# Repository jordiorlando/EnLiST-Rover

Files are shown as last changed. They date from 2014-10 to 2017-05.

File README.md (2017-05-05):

EnLiST-Rover
============

EnLiST Rover modelled on the Curiosity Rover. The goal is to use it as a teaching platform for middle and high school students.

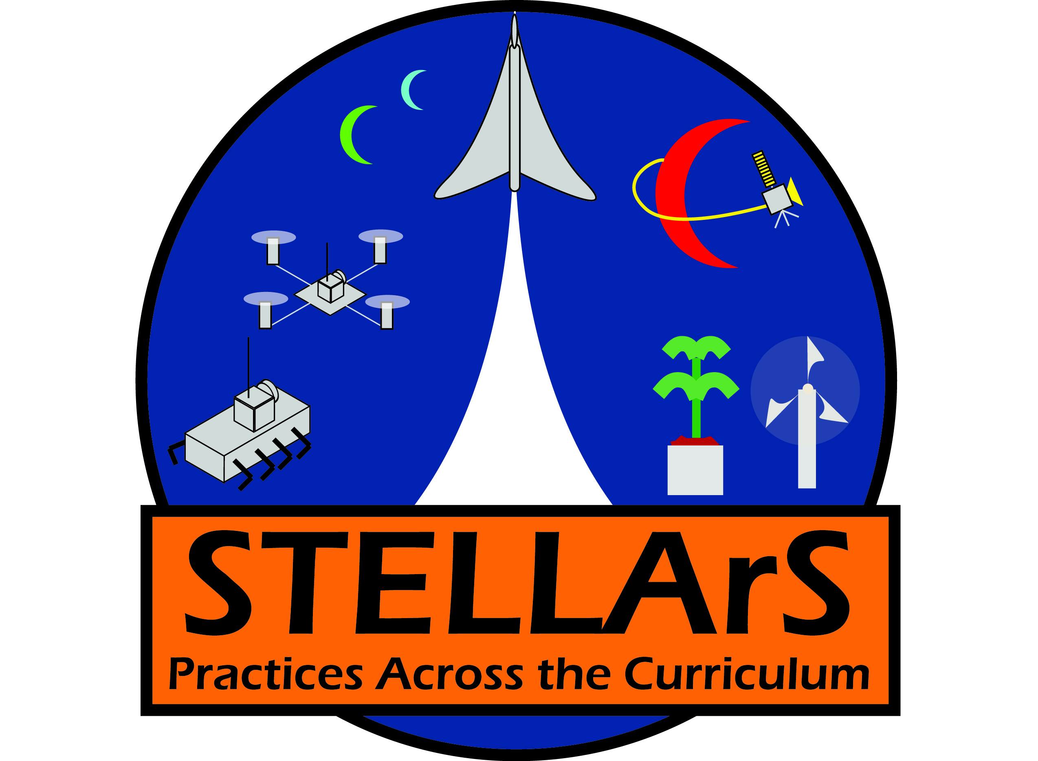
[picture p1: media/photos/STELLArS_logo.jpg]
STELLArS Logo


## Motor Controller
[Motor Controller Test Video](https://www.youtube.com/watch?v=swelm4EhzFY) demonstrating PC simulation and gamepad interface.

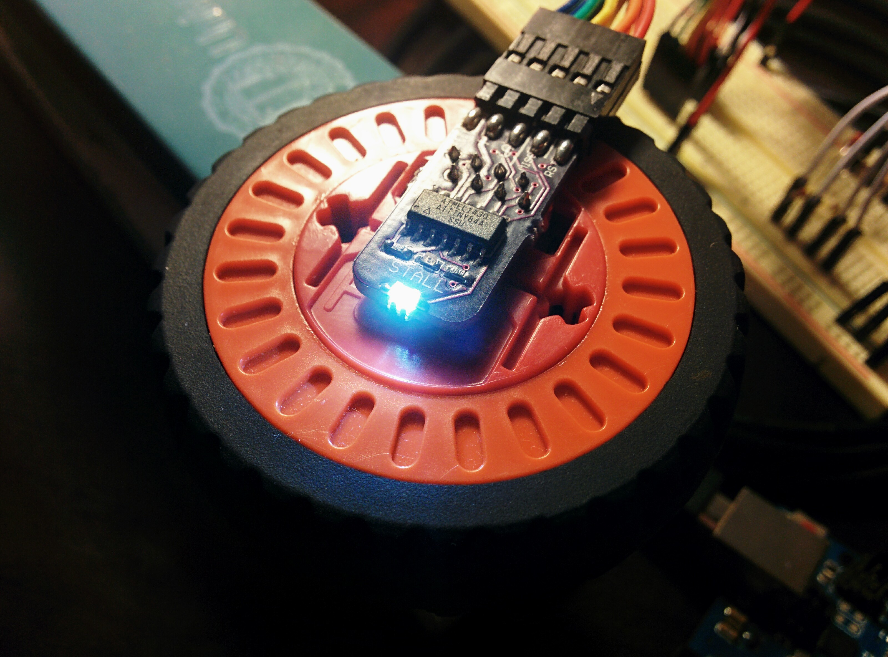
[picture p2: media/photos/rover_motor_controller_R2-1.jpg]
Motor Controller R2 1

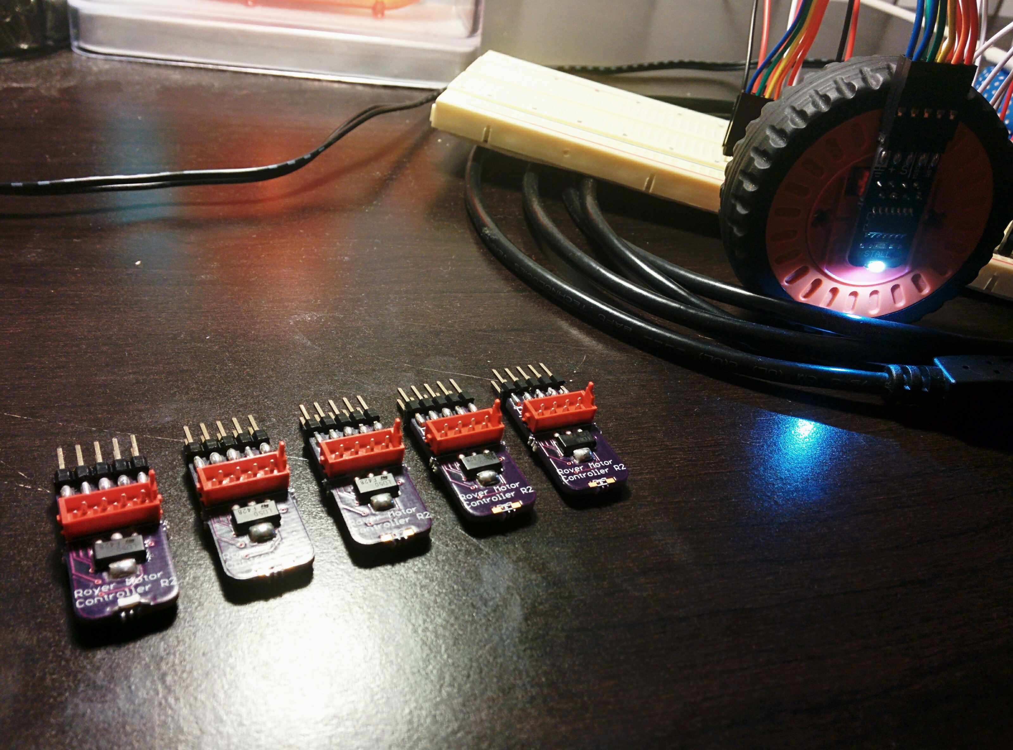
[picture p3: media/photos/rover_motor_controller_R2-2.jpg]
Motor Controller R2 2


## Prototype Photos
Rover Prototype 1
Rover Prototype 2
Rover Prototype 3

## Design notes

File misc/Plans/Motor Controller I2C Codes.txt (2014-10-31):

Standby         - 0x00
Freewheel       - 0x01
Brake           - 0x02
Turn Forwards   - 0x03
Turn Backwards  - 0x04
Set Servo       - 0x05
Turn Off Lamp   - 0x06
Turn On Lamp    - 0x07

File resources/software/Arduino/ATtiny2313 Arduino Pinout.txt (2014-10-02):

ATtiny2313 Arduino Pinout
			  __  __
			 |  \/  |
	   RST	1|		|20	 VCC
		D0	2|		|19	 D16
		D1	3|		|18	 D15
		D2	4|		|17	 D14
		D3	5|		|16	 D13~
		D4	6|		|15	 D12~
		D5	7|		|14	 D11~
		D6	8|		|13	 D10
	   ~D7	9|		|12	 D9
	   GND 10|		|11  D8
	   		 |______|

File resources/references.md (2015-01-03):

Chassis:<br>
http://www.creative-robotics.com/bmdsresources

BBB:<br>
https://learn.sparkfun.com/tutorials/i2c<br>
http://derekmolloy.ie/beaglebone/beaglebone-an-i2c-tutorial-interfacing-to-a-bma180-accelerometer/

http://derekmolloy.ie/beaglebone-images-video-and-opencv/<br>
http://derekmolloy.ie/beaglebone/beaglebone-video-capture-and-image-processing-on-embedded-linux-using-opencv/

http://www.element14.com/community/community/designcenter/single-board-computers/next-gen_beaglebone/blog/2013/08/10/bbb--rechargeable-on-board-battery-system

Motor Controllers:<br>
http://highlowtech.org/?p=1695

http://playground.arduino.cc/Code/USIi2c<br>
http://www.instructables.com/id/ATTiny-USI-I2C-The-detailed-in-depth-and-infor/

http://playground.arduino.cc/Code/PIDLibrary

https://code.google.com/p/adaencoder/<br>
http://www.pjrc.com/teensy/td_libs_Encoder.html<br>
http://thewanderingengineer.com/2013/05/05/rotary-encoder-with-the-attiny85/<br>
http://runawaybrainz.blogspot.com/2013/08/avr-attiny-2313-v-usb-media-volume.html

Servos:<br>
http://www.adafruit.com/products/815

Dust Sensor:<br>
http://www.howmuchsnow.com/arduino/airquality/<br>
http://arduinodev.woofex.net/2012/12/01/standalone-sharp-dust-sensor/<br>
https://www.sparkfun.com/datasheets/Sensors/gp2y1010au_e.pdf

Web Frontend:<br>
http://httpd.apache.org/<br>
http://ami.responsivedesign.is/<br>
http://www.google.com/design/spec/material-design/introduction.html<br>
https://www.polymer-project.org/<br>
https://developers.google.com/blockly/<br>
https://github.com/nnnick/Chart.js<br>
https://github.com/flatiron/director

http://maklesoft.github.io/padlock/<br>
https://github.com/MaKleSoft/shape-shifter<br>
http://codepen.io/anon/pen/qJDsg<br>
http://codepen.io/kabadesu/pen/qvdzK<br>
https://github.com/Battlefy/paper-vertical-tabs

Misc:<br>
http://blog.oscarliang.net/program-attiny2313-using-arduino/

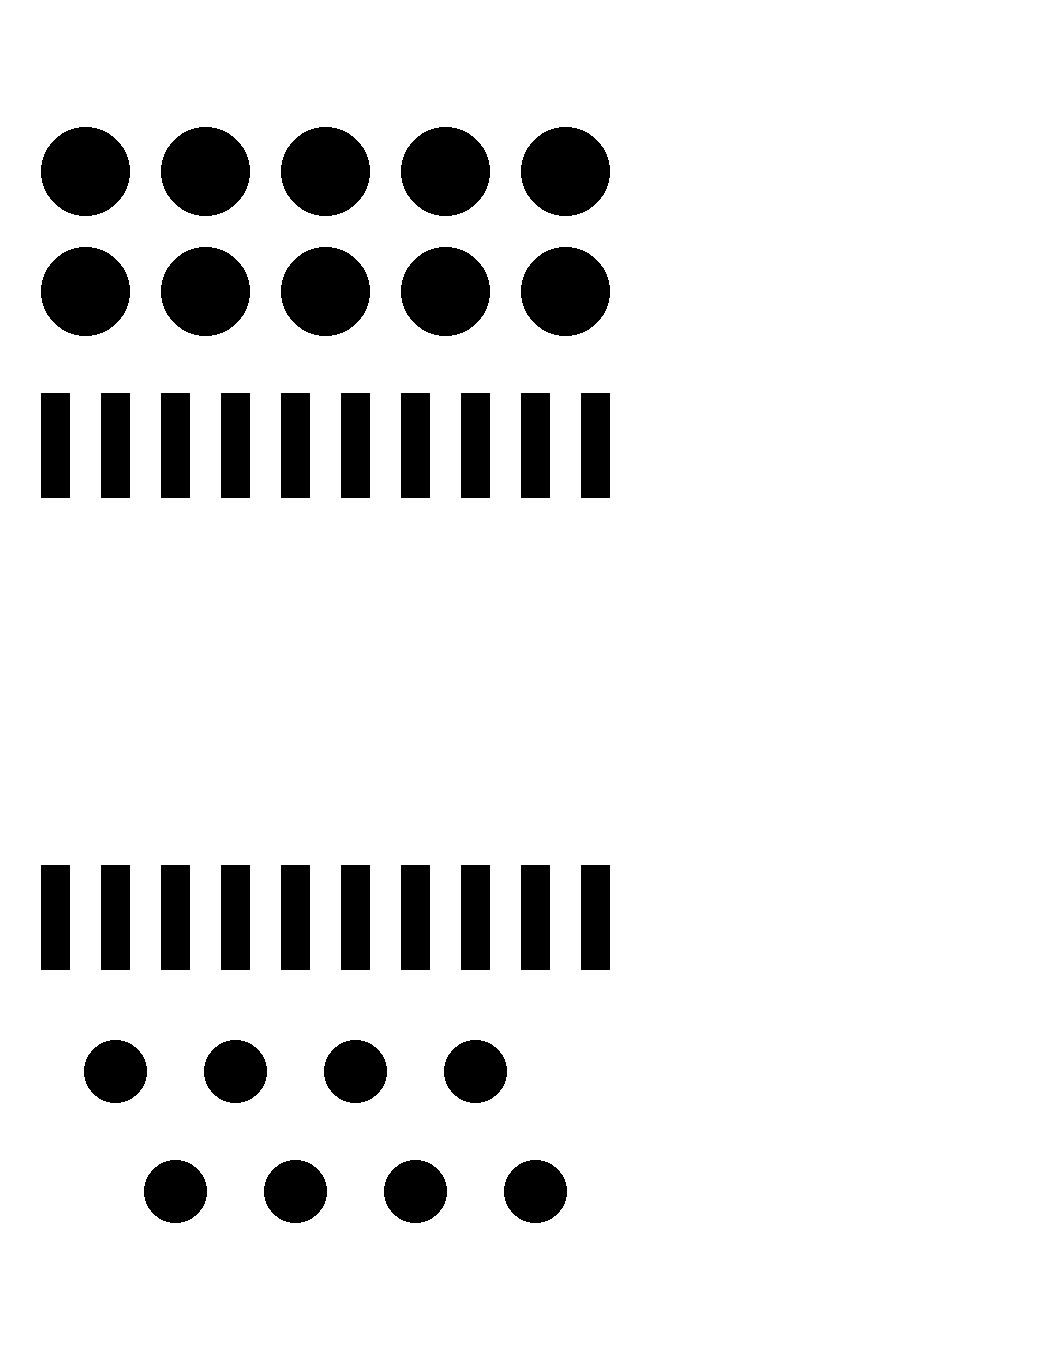
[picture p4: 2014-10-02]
hardware/Eagle/Rover Motor Controller/eagleUp/eagleUp_Rover Motor Controller_bottom_mask.png

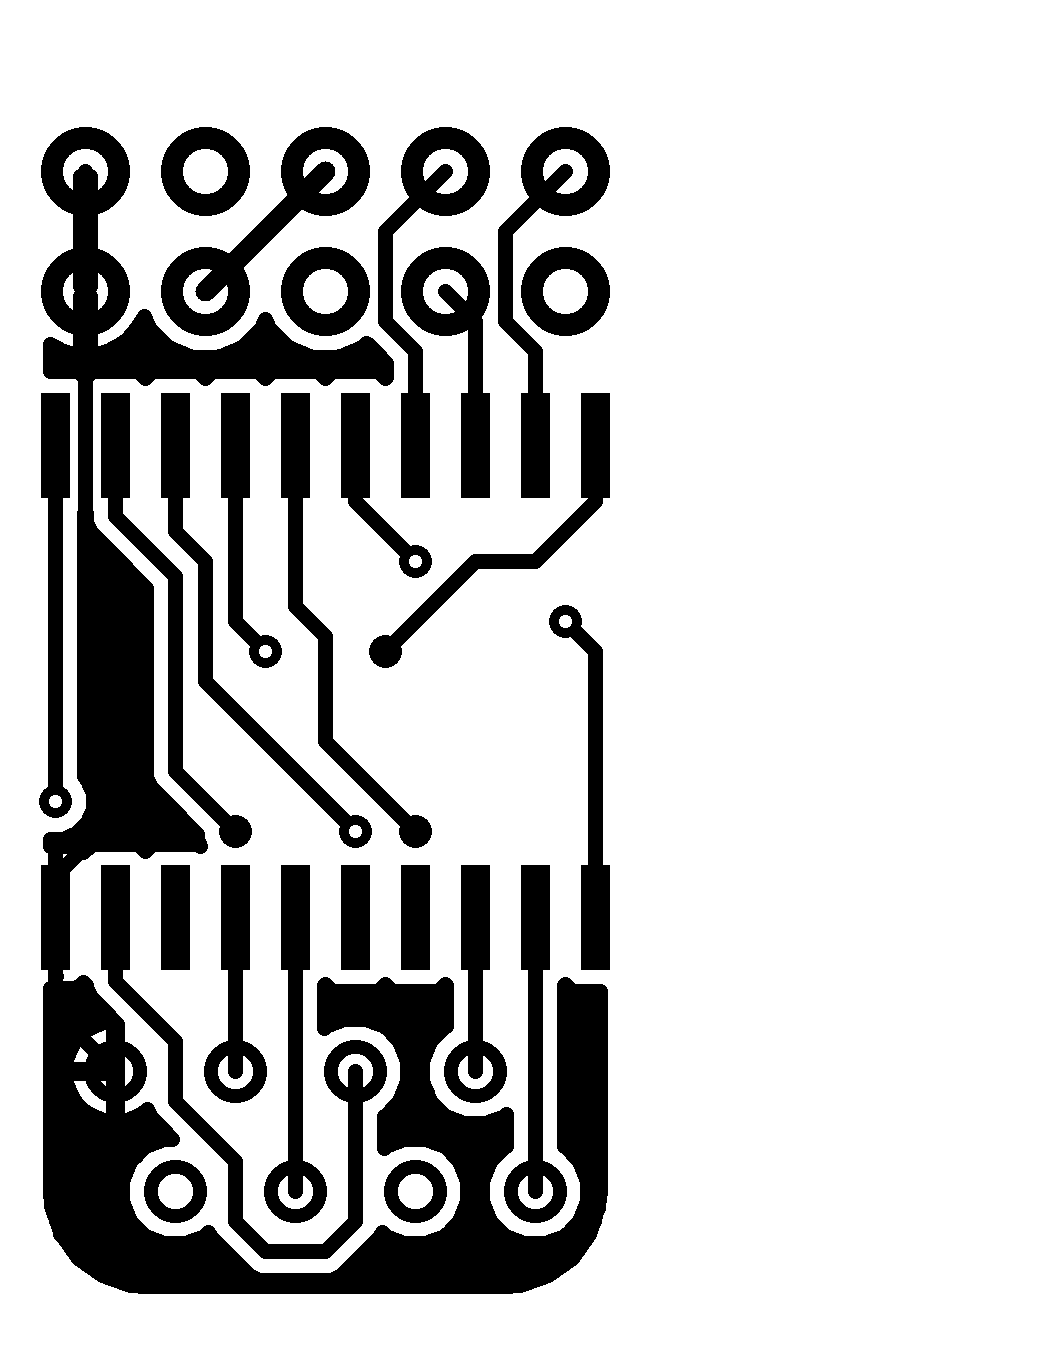
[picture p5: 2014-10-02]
hardware/Eagle/Rover Motor Controller/eagleUp/eagleUp_Rover Motor Controller_bottom.png

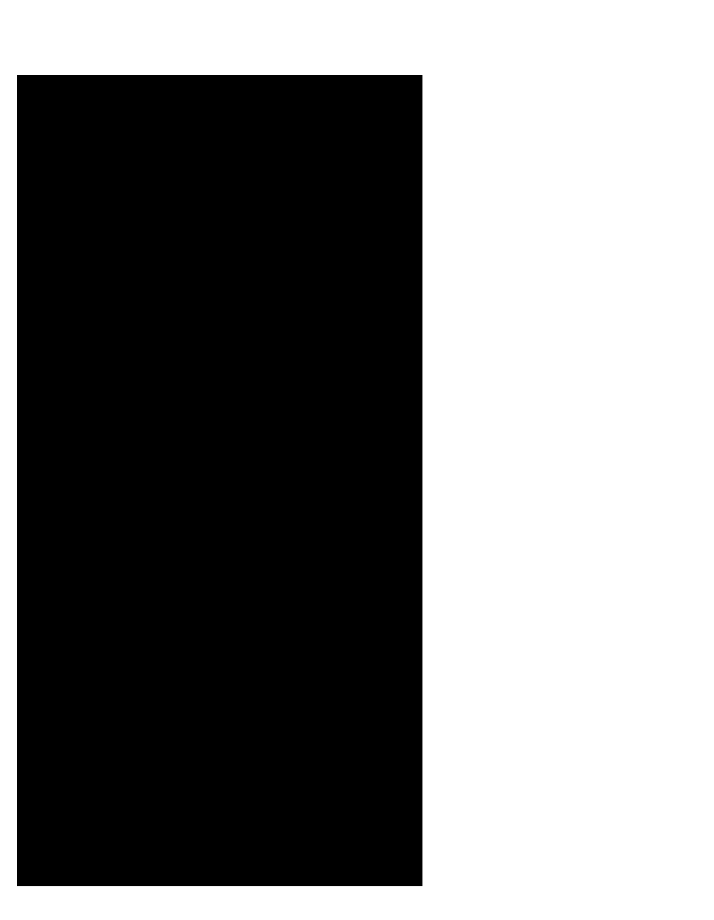
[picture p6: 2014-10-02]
hardware/Eagle/Rover Motor Controller/eagleUp/eagleUp_Rover Motor Controller_imagesize.png

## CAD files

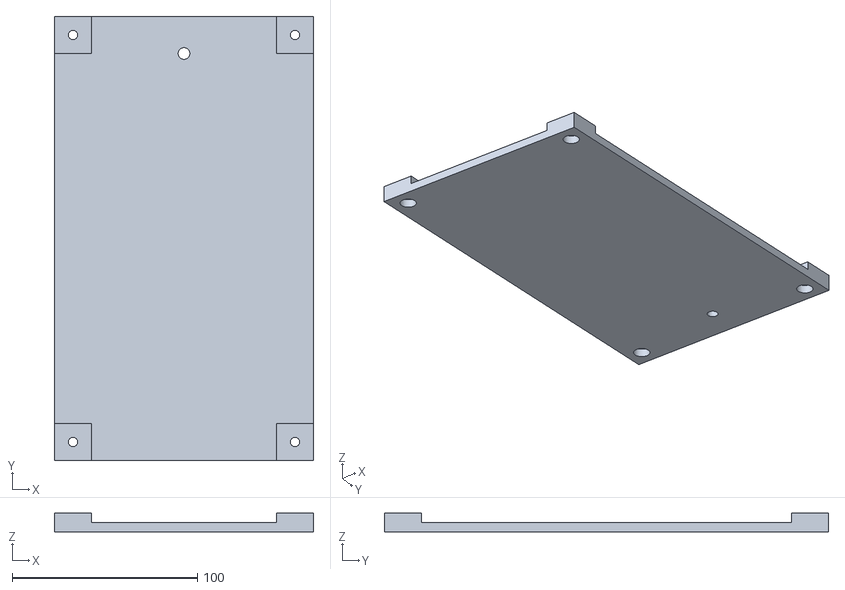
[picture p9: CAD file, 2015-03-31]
hardware/Sketchup/2015-03-31 Print/STL/Lid.stl
140.0 x 240.0 x 10.0

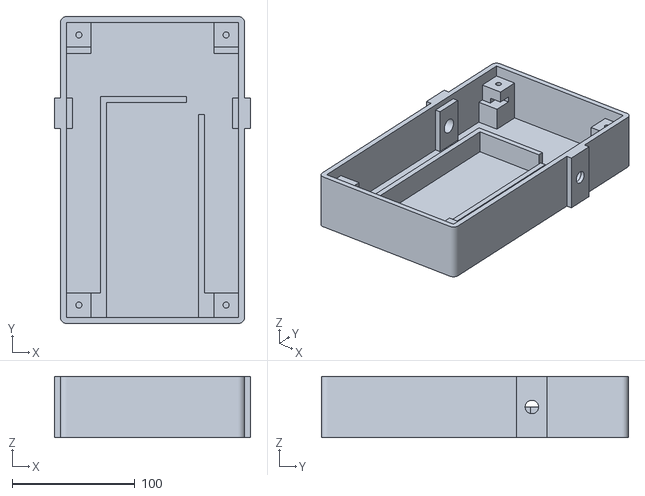
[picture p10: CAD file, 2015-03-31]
hardware/Sketchup/2015-03-31 Print/STL/Body.stl
160.0 x 250.0 x 50.0

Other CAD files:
Sketchup/Rover.skp
hardware/Sketchup/2015-03-31 Print/Body.skp
hardware/Sketchup/2015-03-31 Print/Lid.skp
hardware/Sketchup/Rover.skp

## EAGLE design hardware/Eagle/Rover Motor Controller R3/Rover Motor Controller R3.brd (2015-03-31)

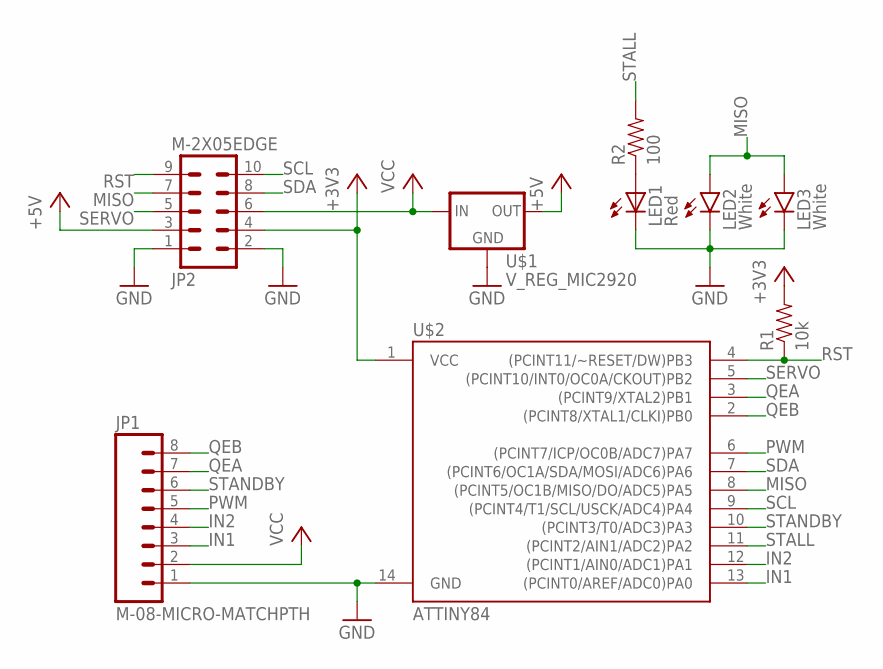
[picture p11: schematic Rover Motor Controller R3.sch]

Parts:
JP1: M-08-MICRO-MATCHPTH; M-08-MICRO-MATCH-PTH
JP2: M-2X05EDGE; M-2X05-0.1-EDGE
LED1: Red; SML0603
LED2, LED3: White; LED-SMD-RA
R1: 10k; R0603
R2: 100; R0603
U$1: V_REG_MIC2920; SOT223
U$2: ATTINY84; SO14

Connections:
+3V3: JP2.4, R1.2, U$2.1 (VCC)
+5V: JP2.3, U$1.3 (OUT)
GND: JP1.1, JP2.1, JP2.2, LED1.C, LED2.C, LED3.C, U$1.2 (GND), U$2.14 (GND)
IN1: JP1.3, U$2.13 ((PCINT0/AREF/ADC0)PA0)
IN2: JP1.4, U$2.12 ((PCINT1/AIN0/ADC1)PA1)
MISO: JP2.7, LED2.A, LED3.A, U$2.8 ((PCINT5/OC1B/MISO/DO/ADC5)PA5)
unnamed: LED1.A, R2.1
PWM: JP1.5, U$2.6 ((PCINT7/ICP/OC0B/ADC7)PA7)
QEA: JP1.7, U$2.3 ((PCINT9/XTAL2)PB1)
QEB: JP1.8, U$2.2 ((PCINT8/XTAL1/CLKI)PB0)
RST: JP2.9, R1.1, U$2.4 ((PCINT11/~RESET/DW)PB3)
SCL: JP2.10, U$2.9 ((PCINT4/T1/SCL/USCK/ADC4)PA4)
SDA: JP2.8, U$2.7 ((PCINT6/OC1A/SDA/MOSI/ADC6)PA6)
SERVO: JP2.5, U$2.5 ((PCINT10/INT0/OC0A/CKOUT)PB2)
STALL: R2.2, U$2.11 ((PCINT2/AIN1/ADC2)PA2)
STANDBY: JP1.6, U$2.10 ((PCINT3/T0/ADC3)PA3)
VCC: JP1.2, JP2.6, U$1.1 (IN)

Board: 2 copper layers, 9 parts (3 on the bottom side), 17 nets, no tracks yet.

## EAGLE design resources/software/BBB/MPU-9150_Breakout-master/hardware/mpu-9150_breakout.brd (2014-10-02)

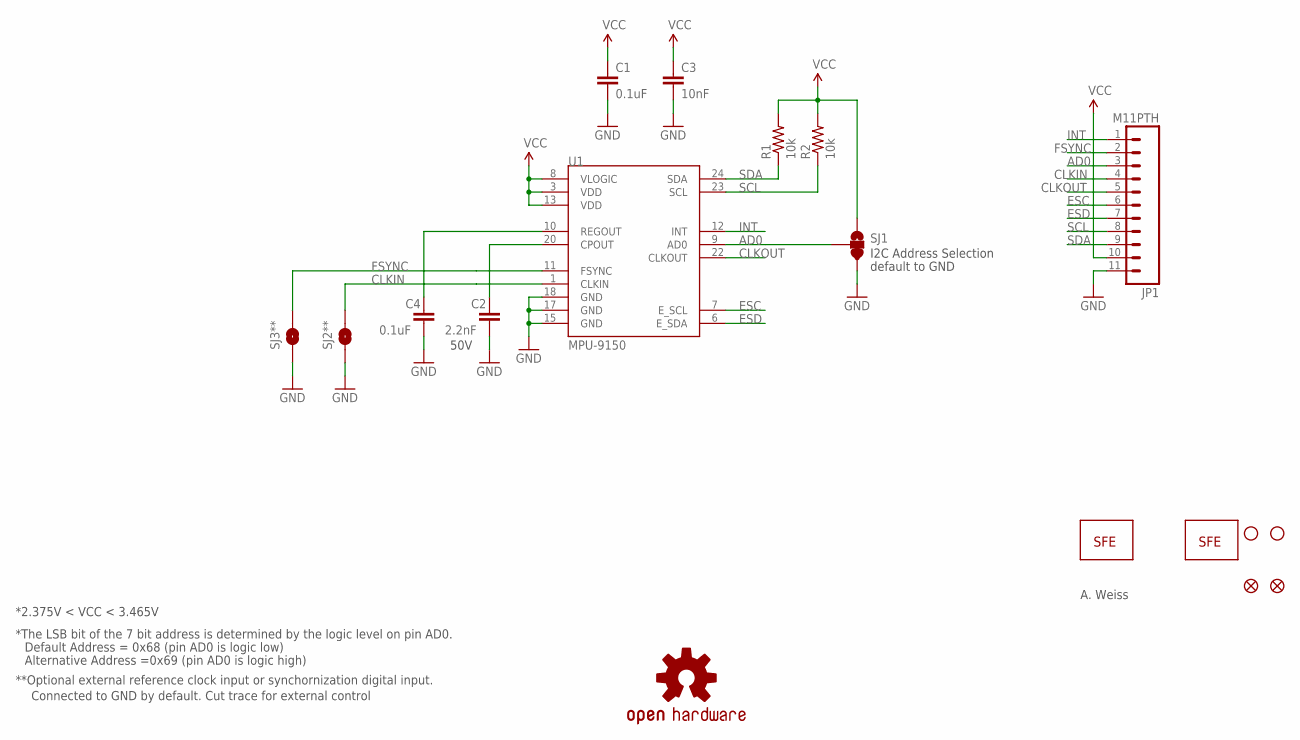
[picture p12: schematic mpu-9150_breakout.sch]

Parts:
C1, C4: 0.1uF; 0402-CAP
C2: 2.2nF; 0402-CAP
C3: 10nF; 0402-CAP
JP1: M11PTH; 1X11
JP2, JP3: STAND-OFF
JP4: LOGO-SFENW2; SFE-NEW-WEB
JP6: LOGO-SFESK; SFE-LOGO-FLAME
JP7, JP8: FIDUCIALUFIDUCIAL; MICRO-FIDUCIAL
R1, R2: 10k; 0402-RES
SJ1: SOLDERJUMPER_2WAYPASTE2&3; SJ_3_PASTE2&3
SJ2**, SJ3**: SOLDERJUMPERTRACE; SJ_2S-TRACE
U1: MPU-9150; QFN-24-NP
U$1: OSHW-LOGOS; OSHW-LOGO-S

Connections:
AD0: JP1.3, SJ1.2, U1.9 (AD0)
CLKIN: JP1.4, SJ2**.2, U1.1 (CLKIN)
CLKOUT: JP1.5, U1.22 (CLKOUT)
ESC: JP1.6, U1.7 (E_SCL)
ESD: JP1.7, U1.6 (E_SDA)
FSYNC: JP1.2, SJ3**.2, U1.11 (FSYNC)
GND: C1.2, C2.2, C3.2, C4.2, JP1.11, SJ1.3, SJ2**.1, SJ3**.1, U1.15 (GND), U1.17 (GND), U1.18 (GND)
INT: JP1.1, U1.12 (INT)
unnamed: C2.1, U1.20 (CPOUT)
unnamed: C4.1, U1.10 (REGOUT)
SCL: JP1.8, R2.1, U1.23 (SCL)
SDA: JP1.9, R1.1, U1.24 (SDA)
VCC: C1.1, C3.1, JP1.10, R1.2, R2.2, SJ1.1, U1.3 (VDD), U1.8 (VLOGIC), U1.13 (VDD)

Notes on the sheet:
50V
I2C Address Selection
**Optional external reference clock input or synchornization digital input.
Connected to GND by default. Cut trace for external control
Default Address = 0x68 (pin AD0 is logic low)
Alternative Address =0x69 (pin AD0 is logic high)
*The LSB bit of the 7 bit address is determined by the logic level on pin AD0.
default to GND
A. Weiss
*2.375V < VCC < 3.465V

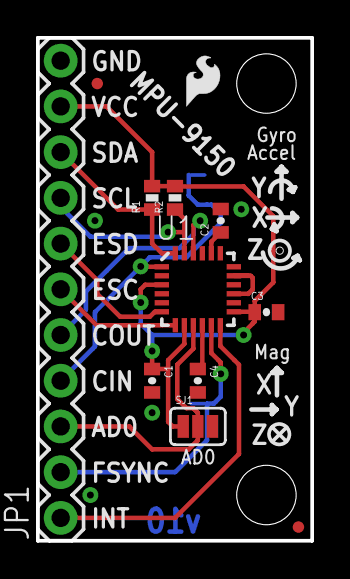
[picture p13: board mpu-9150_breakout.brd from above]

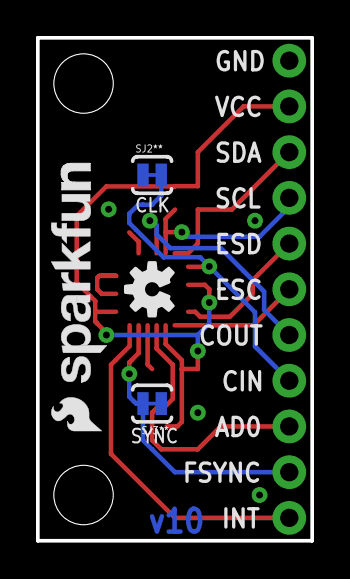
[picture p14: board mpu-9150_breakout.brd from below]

Board: 2 copper layers, 15.2 x 27.9 mm, 19 parts (5 on the bottom side), 13 nets.

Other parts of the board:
JP5: LOGO-SFESK; SFE-LOGO-FLAME

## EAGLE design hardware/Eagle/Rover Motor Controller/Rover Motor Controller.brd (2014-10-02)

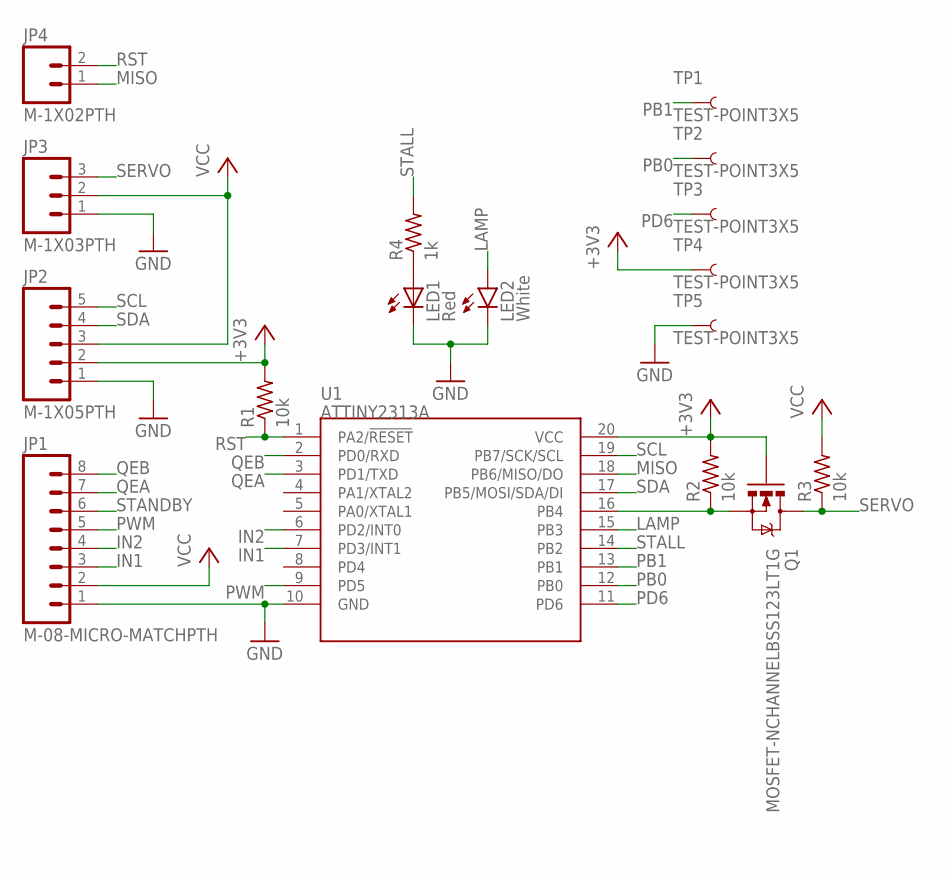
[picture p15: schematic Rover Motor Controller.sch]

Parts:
JP1: M-08-MICRO-MATCHPTH; M-08-MICRO-MATCH-PTH
JP2: M-1X05PTH; M-1X05-0.1-PTH
JP3: M-1X03PTH; M-1X03-0.1-PTH
JP4: M-1X02PTH; M-1X02-0.1-PTH
LED1: Red; SML0603
LED2: White; LED-SMD-RA
Q1: MOSFET-NCHANNELBSS123LT1G; SOT23-3
R1, R2, R3: 10k; R0603
R4: 1k; R0603
TP1, TP2, TP3, TP4, TP5: TEST-POINT3X5; PAD.03X.05
U1: ATTINY2313A; SOP20W

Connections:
+3V3: JP2.2, Q1.1 (G), R1.2, R2.2, TP4.P$1, U1.20 (VCC)
GND: JP1.1, JP2.1, JP3.1, LED1.C, LED2.C, TP5.P$1, U1.10 (GND)
IN1: JP1.3, U1.7 (PD3/INT1)
IN2: JP1.4, U1.6 (PD2/INT0)
LAMP: LED2.A, U1.15 (PB3)
MISO: JP4.1, U1.18 (PB6/MISO/DO)
unnamed: Q1.2 (S), R2.1, U1.16 (PB4)
unnamed: LED1.A, R4.1
PB0: TP2.P$1, U1.12 (PB0)
PB1: TP1.P$1, U1.13 (PB1)
PD6: TP3.P$1, U1.11 (PD6)
PWM: JP1.5, U1.9 (PD5)
QEA: JP1.7, U1.3 (PD1/TXD)
QEB: JP1.8, U1.2 (PD0/RXD)
RST: JP4.2, R1.1, U1.1 (PA2/!RESET)
SCL: JP2.5, U1.19 (PB7/SCK/SCL)
SDA: JP2.4, U1.17 (PB5/MOSI/SDA/DI)
SERVO: JP3.3, Q1.3 (D), R3.1
STALL: R4.2, U1.14 (PB2)
STANDBY: JP1.6
VCC: JP1.2, JP2.3, JP3.2, R3.2

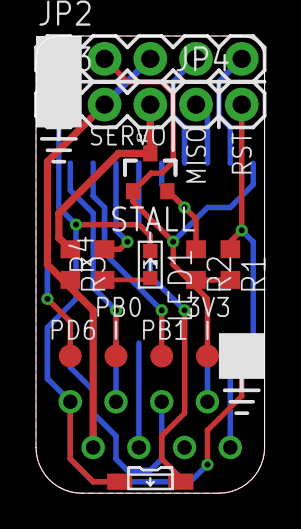
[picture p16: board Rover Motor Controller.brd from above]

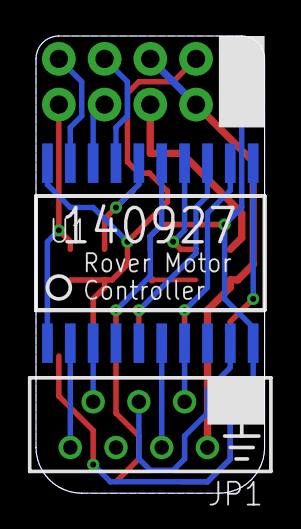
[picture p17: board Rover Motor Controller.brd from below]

Board: 2 copper layers, 12.7 x 25.4 mm, 17 parts (2 on the bottom side), 20 nets.

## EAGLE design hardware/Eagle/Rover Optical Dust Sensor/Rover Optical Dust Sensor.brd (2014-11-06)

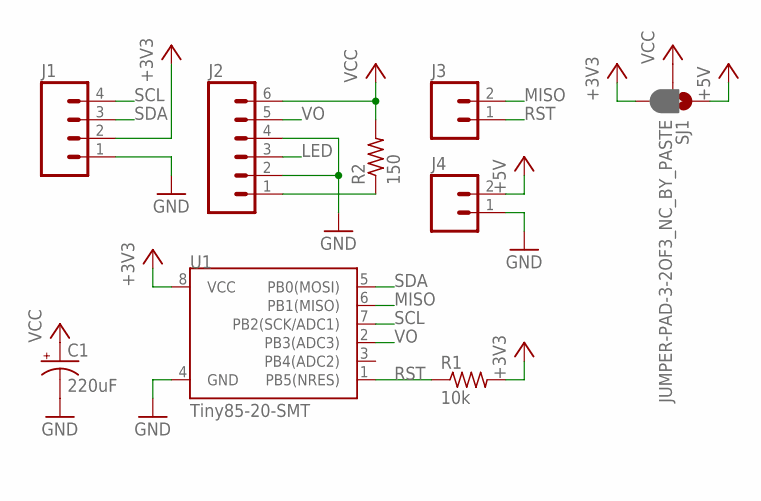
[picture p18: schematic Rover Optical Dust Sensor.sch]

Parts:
C1: 220uF; CPOL-RADIAL-100UF-25V
J1: 1X04M-0.1-PTH; M-1X04-0.1-PTH
J2: 1X06M-0.1-PTH; M-1X06-0.1-PTH
J3, J4: 1X02M-0.1-PTH; M-1X02-0.1-PTH
R1: 10k; R0603
R2: 150; R0603
SJ1: JUMPER-PAD-3-2OF3_NC_BY_PASTE; PAD-JUMPER-3-2OF3_NC_BY_PASTE_YES_SILK_FULL_BOX
U1: Tiny85-20-SMT; SO08-EIAJ

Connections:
+3V3: J1.2, R1.2, SJ1.3, U1.8 (VCC)
+5V: J4.2, SJ1.1
GND: C1.2 (-), J1.1, J2.2, J2.4, J4.1, U1.4 (GND)
LED: J2.3
MISO: J3.2, U1.6 (PB1(MISO))
unnamed: J2.1, R2.1
RST: J3.1, R1.1, U1.1 (PB5(NRES))
SCL: J1.4, U1.7 (PB2(SCK/ADC1))
SDA: J1.3, U1.5 (PB0(MOSI))
VCC: C1.1 (+), J2.6, R2.2, SJ1.2
VO: J2.5, U1.2 (PB3(ADC3))

Board: 2 copper layers, 9 parts (1 on the bottom side), 10 nets, no tracks yet.

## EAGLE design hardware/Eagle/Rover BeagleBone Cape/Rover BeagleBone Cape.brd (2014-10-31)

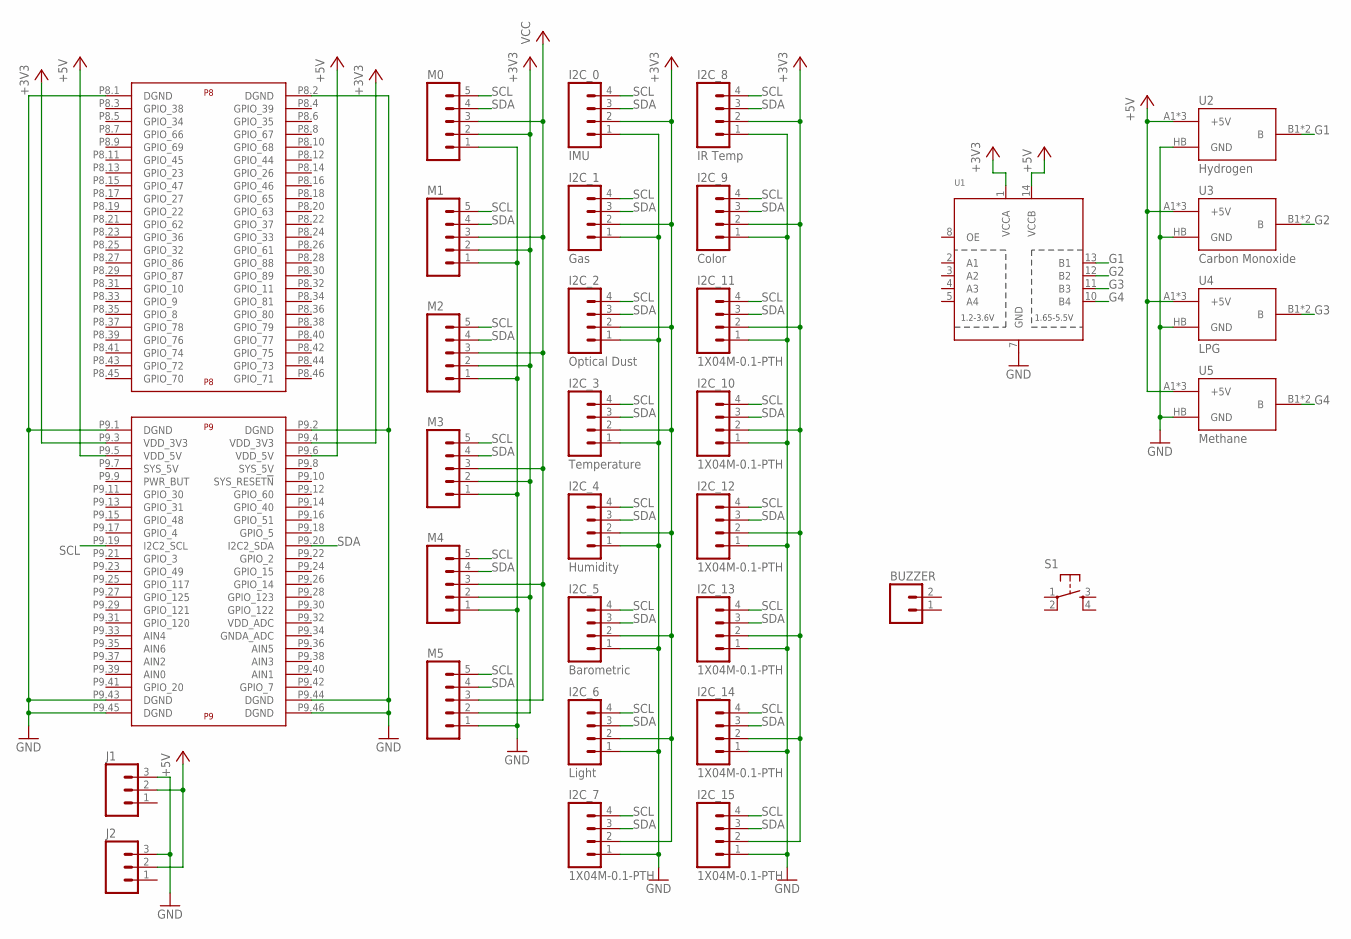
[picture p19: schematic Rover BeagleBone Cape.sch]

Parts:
BUZZER: 1X02M-0.1-PTH; M-1X02-0.1-PTH
I2C_0: IMU; M-1X04-0.1-PTH
I2C_1: Gas; M-1X04-0.1-PTH
I2C_2: Optical Dust; M-1X04-0.1-PTH
I2C_3: Temperature; M-1X04-0.1-PTH
I2C_4: Humidity; M-1X04-0.1-PTH
I2C_5: Barometric; M-1X04-0.1-PTH
I2C_6: Light; M-1X04-0.1-PTH
I2C_7, I2C_10, I2C_11, I2C_12, I2C_13, I2C_14, I2C_15: 1X04M-0.1-PTH; M-1X04-0.1-PTH
I2C_8: IR Temp; M-1X04-0.1-PTH
I2C_9: Color; M-1X04-0.1-PTH
J1, J2: 1X03M-0.1-PTH; M-1X03-0.1-PTH
M0, M1, M2, M3, M4, M5: 1X05M-0.1-PTH; M-1X05-0.1-PTH
S1: SWITCH-TACTILESMD; SWITCH-TACTILE-SMD
U1: TXB0104PWR; TSSOP14
U2: Hydrogen; MQ-X
U3: Carbon Monoxide; MQ-X
U4: LPG; MQ-X
U5: Methane; MQ-X
U$1: BEAGLE_BONE_BLACK_CAPE

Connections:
+3V3: I2C_0.2, I2C_1.2, I2C_2.2, I2C_3.2, I2C_4.2, I2C_5.2, I2C_6.2, I2C_7.2, I2C_8.2, I2C_9.2, I2C_10.2, I2C_11.2, I2C_12.2, I2C_13.2, I2C_14.2, I2C_15.2, M0.2, M1.2, M2.2, M3.2, M4.2, M5.2, U1.1 (VCCA), U$1.P9.3 (VDD_3V3), U$1.P9.4 (VDD_3V3)
+5V: J1.2, J2.2, U1.14 (VCCB), U2.A1 (+5V), U2.A2 (+5V), U2.HA (+5V), U3.A1 (+5V), U3.A2 (+5V), U3.HA (+5V), U4.A1 (+5V), U4.A2 (+5V), U4.HA (+5V), U5.A1 (+5V), U5.A2 (+5V), U5.HA (+5V), U$1.P9.5 (VDD_5V), U$1.P9.6 (VDD_5V)
G1: U1.13 (B1), U2.B1 (B), U2.B2 (B)
G2: U1.12 (B2), U3.B1 (B), U3.B2 (B)
G3: U1.11 (B3), U4.B1 (B), U4.B2 (B)
G4: U1.10 (B4), U5.B1 (B), U5.B2 (B)
GND: I2C_0.1, I2C_1.1, I2C_2.1, I2C_3.1, I2C_4.1, I2C_5.1, I2C_6.1, I2C_7.1, I2C_8.1, I2C_9.1, I2C_10.1, I2C_11.1, I2C_12.1, I2C_13.1, I2C_14.1, I2C_15.1, J1.3, J2.3, M0.1, M1.1, M2.1, M3.1, M4.1, M5.1, U1.7 (GND), U2.HB (GND), U3.HB (GND), U4.HB (GND), U5.HB (GND), U$1.P8.1 (DGND), U$1.P8.2 (DGND), U$1.P9.1 (DGND), U$1.P9.2 (DGND), U$1.P9.43 (DGND), U$1.P9.44 (DGND), U$1.P9.45 (DGND), U$1.P9.46 (DGND)
SCL: I2C_0.4, I2C_1.4, I2C_2.4, I2C_3.4, I2C_4.4, I2C_5.4, I2C_6.4, I2C_7.4, I2C_8.4, I2C_9.4, I2C_10.4, I2C_11.4, I2C_12.4, I2C_13.4, I2C_14.4, I2C_15.4, M0.5, M1.5, M2.5, M3.5, M4.5, M5.5, U$1.P9.19 (I2C2_SCL)
SDA: I2C_0.3, I2C_1.3, I2C_2.3, I2C_3.3, I2C_4.3, I2C_5.3, I2C_6.3, I2C_7.3, I2C_8.3, I2C_9.3, I2C_10.3, I2C_11.3, I2C_12.3, I2C_13.3, I2C_14.3, I2C_15.3, M0.4, M1.4, M2.4, M3.4, M4.4, M5.4, U$1.P9.20 (I2C2_SDA)
VCC: M0.3, M1.3, M2.3, M3.3, M4.3, M5.3

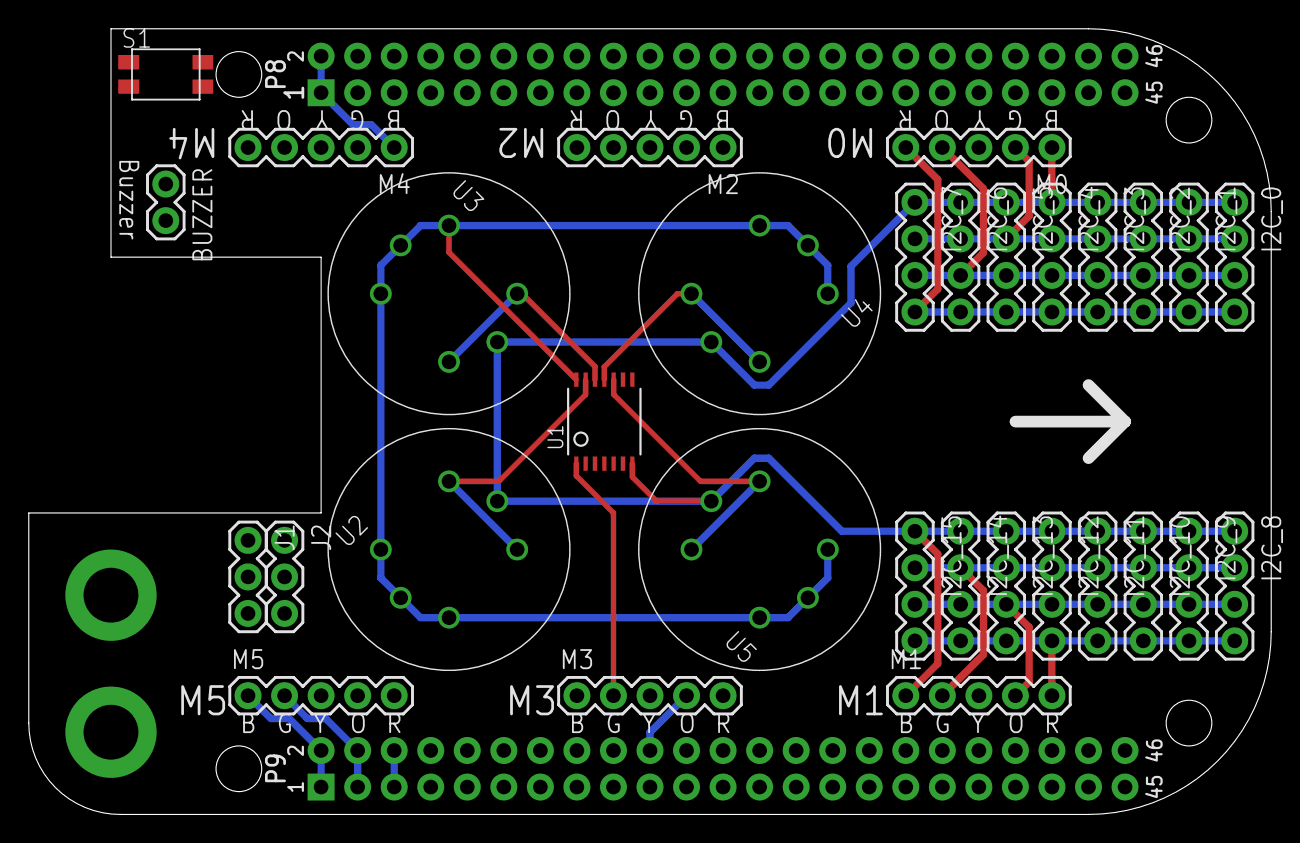
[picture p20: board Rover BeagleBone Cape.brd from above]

Board: 2 copper layers, 86.4 x 54.6 mm, 32 parts (0 on the bottom side), 10 nets.

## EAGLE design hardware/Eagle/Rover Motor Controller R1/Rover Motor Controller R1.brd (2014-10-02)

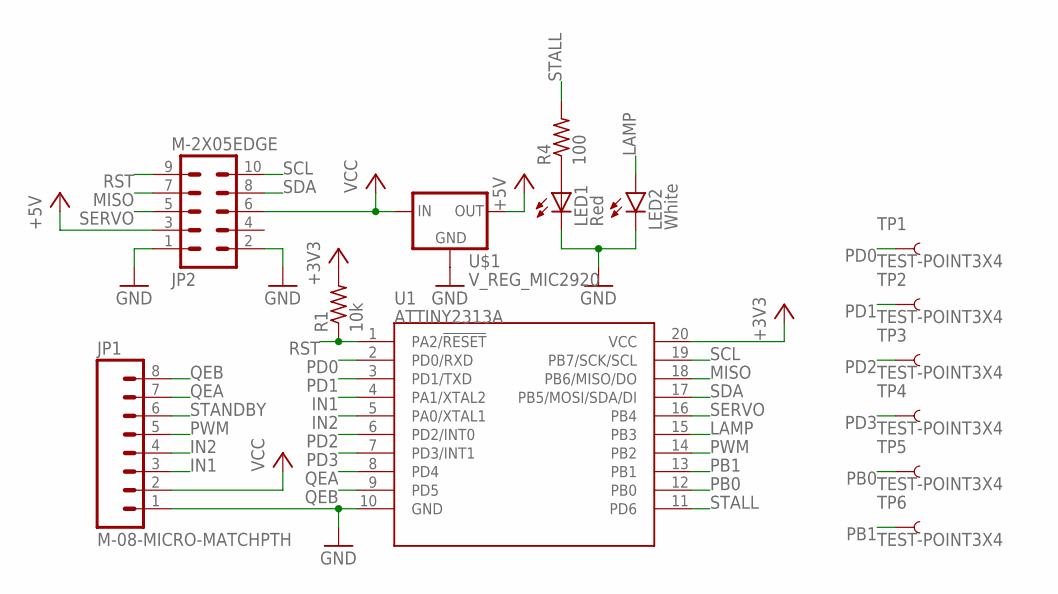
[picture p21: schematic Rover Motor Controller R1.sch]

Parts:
JP1: M-08-MICRO-MATCHPTH; M-08-MICRO-MATCH-PTH
JP2: M-2X05EDGE; M-2X05-0.1-EDGE
LED1: Red; SML0603
LED2: White; LED-SMD-RA
R1: 10k; R0603
R4: 100; R0603
TP1, TP2, TP3, TP4, TP5, TP6: TEST-POINT3X4; PAD.03X.04
U1: ATTINY2313A; SOP20W
U$1: V_REG_MIC2920; SOT223

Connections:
+3V3: R1.2, U1.20 (VCC)
+5V: JP2.3, U$1.3 (OUT)
GND: JP1.1, JP2.1, JP2.2, LED1.C, LED2.C, U1.10 (GND), U$1.2 (GND)
IN1: JP1.3, U1.4 (PA1/XTAL2)
IN2: JP1.4, U1.5 (PA0/XTAL1)
LAMP: LED2.A, U1.15 (PB3)
MISO: JP2.7, U1.18 (PB6/MISO/DO)
unnamed: LED1.A, R4.1
PB0: TP5.P$1, U1.12 (PB0)
PB1: TP6.P$1, U1.13 (PB1)
PD0: TP1.P$1, U1.2 (PD0/RXD)
PD1: TP2.P$1, U1.3 (PD1/TXD)
PD2: TP3.P$1, U1.6 (PD2/INT0)
PD3: TP4.P$1, U1.7 (PD3/INT1)
PWM: JP1.5, U1.14 (PB2)
QEA: JP1.7, U1.8 (PD4)
QEB: JP1.8, U1.9 (PD5)
RST: JP2.9, R1.1, U1.1 (PA2/!RESET)
SCL: JP2.10, U1.19 (PB7/SCK/SCL)
SDA: JP2.8, U1.17 (PB5/MOSI/SDA/DI)
SERVO: JP2.5, U1.16 (PB4)
STALL: R4.2, U1.11 (PD6)
STANDBY: JP1.6
VCC: JP1.2, JP2.6, U$1.1 (IN)

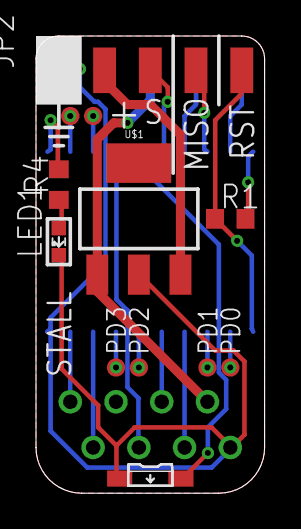
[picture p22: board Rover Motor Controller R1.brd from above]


Board: 2 copper layers, 12.7 x 25.4 mm, 14 parts (2 on the bottom side), 23 nets.

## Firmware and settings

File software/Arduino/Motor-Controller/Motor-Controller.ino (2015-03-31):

#include <TinyWireS.h>
#include <TinyServo.h>
#include <PID_v1.h>

// The default buffer size
#ifndef TWI_RX_BUFFER_SIZE
#define TWI_RX_BUFFER_SIZE ( 16 )
#endif

// Change this to a unique address for each controller
#define MOTOR_ADDRESS	0x42

// Size of the I2C register
#define REGSIZE 16

// Pin definitions
#define IN1		0
#define IN2		1
#define STALL	2
#define STANDBY	3
#define LAMP	5
#define PWM		7
#define SERVO	8
#define QEA		9
#define QEB		10

/*	REGISTER LAYOUT

	nI2CReg[0]: speed control
		7:
		6:
		5:
		4:
		3: standby
			0: normal operation
			1: standby
		2: brake mode
			0: brake
			1: freewheel
		1: PID mode
			0: PID off
			1: PID on
		0: requested direction
			0: turn forwards
			1: turn backwards
	nI2CReg[1]: requested wheel speed [0, 255]
	nI2CReg[2]:
		7:
		6:
		5:
		4:
		3:
		2:
		1: stall status
			0: no stall
			1: stall
		0: current direction
			0: forwards
			1: backwards
	nI2CReg[3]: current wheel speed [0, 255]
	nI2CReg[4]: requested servo position [0, 180]
	nI2CReg[5]: requested LAMP brightness
	nI2CReg[6]: lamp mode control
		7:
		6:
		5:
		4:
		3:
		2:
		1:
		0: solid
	nI2CReg[7]:
	nI2CReg[8]:
	nI2CReg[9]:
	nI2CReg[10]: PID P value
	nI2CReg[11]:
	nI2CReg[12]: PID I value
	nI2CReg[13]:
	nI2CReg[14]: PID D value
	nI2CReg[15]:

*/
volatile uint8_t nI2CReg[REGSIZE]; // I2C register
volatile uint8_t nRegPos; // Current I2C register pointer position
volatile bool bNewStuff; // Flag for new I2C data

bool bStandby = true;
bool bBrakeMode = 0;
bool bPIDMode = 0;

// Number of servos
const byte SERVOS = 1;
// Array of servos for library
const byte servoPin[SERVOS] = {SERVO};
// Nice alias for use with the servo library
#define STEERING_SERVO	0

// All required PID variables
double fQE, fPWM, fSpeed, Kp = 2, Ki = 0.1, Kd = 1;
// Declare PID loop
PID speedPID(&fQE, &fPWM, &fSpeed, Kp, Ki, Kd, DIRECT);

void setup() {
	TinyWireS.begin(MOTOR_ADDRESS); // Connect to I2C with specified address
	TinyWireS.onReceive(receiveEvent); // Register receive event
	TinyWireS.onRequest(requestEvent); // Register request event

	setupServos();

	// Initialize PID variables
	fQE = 0;
	fSpeed = 0;

	// Turn the PID controller on
	speedPID.SetMode(AUTOMATIC);
	speedPID.SetSampleTime(10);
	speedPID.SetOutputLimits(-255, 255);

	// Set IO directions
	pinMode(IN1, OUTPUT);
	pinMode(IN2, OUTPUT);
	pinMode(STALL, OUTPUT);
	pinMode(STANDBY, OUTPUT);
	pinMode(LAMP, OUTPUT);
	pinMode(PWM, OUTPUT);
	//pinMode(SERVO, OUTPUT); // DO NOT uncomment this line.
	pinMode(QEA, INPUT);
	pinMode(QEB, INPUT);

	bNewStuff = true; // Initial read
}

void loop() {
	TinyWireS_stop_check(); // Has to run often to detect I2C stop state

	if (bNewStuff) {
		// Update standby
		bStandby = nI2CReg[0] & (1 << 3);
		digitalWrite(STANDBY, !bStandby);

		// Update brake mode
		bBrakeMode = nI2CReg[0] & (1 << 2);

		// Update PID mode
		bPIDMode = nI2CReg[0] & (1 << 1);
		if (bPIDMode) {
			speedPID.SetMode(AUTOMATIC);
		} else {
			speedPID.SetMode(MANUAL);
		}

		// Get requested speed
		if (nI2CReg[0] & 1) {
			fSpeed = nI2CReg[1] * -1;
		} else {
			fSpeed =  nI2CReg[1];
		}

		analogWrite(LAMP, nI2CReg[5]); // Update lamp brightness

		bNewStuff = false; // Reset I2C flag
	}

	if (bStandby) {
	} else {
		if (bPIDMode) {
			fQE = 5; // Test speed reading of 5 (replace with actual QE function call)
			speedPID.Compute(); // Compute PID
		} else {
			fPWM = fSpeed;
		}

		// Update motor speed
		if (fPWM == 0) {
			// Freewheel
			if (bBrakeMode) {
				digitalWrite(IN1, LOW);
				digitalWrite(IN2, LOW);
			} else { // Normal
				digitalWrite(IN1, HIGH);
				digitalWrite(IN2, HIGH);
				digitalWrite(PWM, LOW);
			}
		} else if (fPWM > 0) {
			digitalWrite(IN1, LOW);
			digitalWrite(IN2, HIGH);
			analogWrite(PWM, (uint8_t)fPWM);
		} else {
			digitalWrite(IN1, HIGH);
			digitalWrite(IN2, LOW);
			analogWrite(PWM, (uint8_t)abs(fPWM));
		}

		// Save current speed to register
		if (fQE >= 0) {
			nI2CReg[2] = 0;
			nI2CReg[3] = (uint8_t)fQE;
		} else {
			nI2CReg[2] = 1;
			nI2CReg[3] = (uint8_t)abs(fQE);
		}

		// Set servo position
		moveServo(STEERING_SERVO, nI2CReg[4]);
	}
}

void receiveEvent(uint8_t nNumBytes) {
	if (!nNumBytes || nNumBytes > TWI_RX_BUFFER_SIZE) return; // Sanity check

	// Set I2C register pointer position
	nRegPos = TinyWireS.receive();

	// Leave if this write was only to set the pointer for next read
	if (!--nNumBytes) return;

	while (nNumBytes--) {
		nI2CReg[nRegPos] = TinyWireS.receive(); // Receive byte
		nRegPos++; // Increment I2C register pointer

		// If register position is invalid, fail silently
		if (nRegPos == REGSIZE) {
			while (nNumBytes--) {
				TinyWireS.receive();
			}
			return;
		}
	}

	bNewStuff = true;
}

void requestEvent() {
	TinyWireS.send(nI2CReg[nRegPos]); // Send byte

	// Increment the reg position on each read, and loop back to zero
	nRegPos++;
	if (nRegPos >= REGSIZE) {
		nRegPos = 0;
	}
}

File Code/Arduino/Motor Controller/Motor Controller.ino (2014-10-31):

#include <Wire.h>
#include <PID_v1.h>

#define MOTOR_ADDRESS	0x42

#define IN1		0
#define IN2		1
#define STALL	2
#define STANDBY	3
#define LAMP	5
#define PWM		7
#define SERVO	8
#define QEA		9
#define QEB		10

int16_t nServo;
double fQE, fPWM, fSpeed, P, I, D;
PID speedPID(&fQE, &fPWM, &fSpeed, P, I, D, DIRECT);

void setup()
{
	// connect to I2C with specified address
	Wire.begin(MOTOR_ADDRESS);
	Wire.onReceive(receiveEvent);
	Wire.onRequest(requestEvent);

	// initialize PID variables
	fQE = 0;
	fSpeed = 0;

	// turn the PID controller on
	speedPID.SetMode(AUTOMATIC);
	speedPID.SetSampleTime(10);

	pinMode(IN1, OUTPUT);
	pinMode(IN2, OUTPUT);
	pinMode(STALL, OUTPUT);
	pinMode(STANDBY, OUTPUT);
	pinMode(LAMP, OUTPUT);
	pinMode(PWM, OUTPUT);
	pinMode(SERVO, OUTPUT);
	pinMode(QEA, INPUT);
	pinMode(QEB, INPUT);

	digitalWrite(STANDBY, HIGH);
}

void loop()
{
	fQE = 5;
	speedPID.Compute();
	analogWrite(PWM, (uint8_t)abs(fPWM));
}

void receiveEvent(int nNumBytes)
{
	uint8_t nBytes[nNumBytes];

	for (uint8_t i = 0; i < nNumBytes; i++) {
		nBytes[i] = Wire.read();
	}

	switch (nBytes[0])
	{
		case 0x00: // standby
			digitalWrite(STANDBY, LOW);
			fSpeed = 0;
			break;
		case 0x01: // freewheel
			digitalWrite(IN1, LOW);
			digitalWrite(IN2, LOW);
			digitalWrite(STANDBY, HIGH);
			fSpeed = 0;
			break;
		case 0x02: // brake
			digitalWrite(IN1, HIGH);
			digitalWrite(IN2, HIGH);
			digitalWrite(STANDBY, HIGH);
			fSpeed = 0;
			break;
		case 0x03: // turn forwards
			digitalWrite(IN1, LOW);
			digitalWrite(IN2, HIGH);
			digitalWrite(STANDBY, HIGH);
			fSpeed = (double)nBytes[1];
			break;
		case 0x04: // turn backwards
			digitalWrite(IN1, HIGH);
			digitalWrite(IN2, LOW);
			digitalWrite(STANDBY, HIGH);
			fSpeed = (double)nBytes[1] * -1;
			break;
		case 0x05: // set servo
			nServo = nBytes[2];
			nServo |= (nBytes[1] << 8);
			break;
		case 0x06: // turn off lamp
			digitalWrite(LAMP, LOW);
			break;
		case 0x07: // turn on lamp
			digitalWrite(LAMP, HIGH);
			break;
	}
}

void requestEvent()
{
	uint8_t nSpeed = ((int32_t)fSpeed >> 24) & 0x000000FF;
	Wire.write(nSpeed);
	nSpeed = ((int32_t)fSpeed >> 16) & 0x000000FF;
	Wire.write(nSpeed);
	nSpeed = ((int32_t)fSpeed >> 8) & 0x000000FF;
	Wire.write(nSpeed);
	nSpeed = (int32_t)fSpeed & 0x000000FF;
	Wire.write(nSpeed);

	Wire.write("hello ");
}

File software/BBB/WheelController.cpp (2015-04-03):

#include "WheelController.h"

WheelController::WheelController(deviceManager & manager, int wheel, rovermotion & rm)
 : i2cDevice(WHEEL_BASE_ADDRESS + wheel, manager, 100), rmotion(&rm)
{

  /*
   * Assumption for wheel scheme (6 wheels):
   *
   *     0     x/y
   *
   * 0 ----- 1   ROVER_HEIGHT
   * |   |   |
   * 2 ----- 3   0
   * |   |   |
   * 5 ----- 6   -ROVER_HEIGHT
   *
   * |-------|
   * 3*ROVER_WIDTH
   *
   */

  wattr.wheelnum = wheel;

  if (wattr.wheelnum > 1 && wattr.wheelnum < 4)
    wattr.steerable = STATIONARY;
  else
    wattr.steerable = STEERABLE;

  //even wheels are reversed
  wattr.reverse = (wattr.wheelnum + 1) & 1;

  //wheels alternate sides
  wattr.xpos = (1.5*ROVER_WIDTH) * (-1 + (wattr.wheelnum & 1) * 2);

  //each pair of wheels advance by ROVER_HEIGHT in -y
  wattr.ypos = (wattr.wheelnum / 2) * -ROVER_HEIGHT + ROVER_HEIGHT;

  wattr.centerangle = atan2(wattr.xpos, wattr.ypos);

  wattr.width  = ROVER_WIDTH / 5;
  wattr.height = ROVER_HEIGHT / 5;

}

/*
 * Set the LED lamp brightness from 0 to 255.
 */
void WheelController::setLamp(uint8_t brightness)
{
  data.lampbrightness = brightness;
}

void WheelController::_update()
{
  connected = true;

  smbWriteByte(WHEEL_REG_SPEEDCTRL, data.direction);
  smbWriteByte(WHEEL_REG_REQ_SPEED, data.speed);
  smbWriteByte(WEEEL_REG_SERVO_ANG, data.servoangle);
  smbWriteByte(WEEEL_REG_BRIGHTNESS, data.lampbrightness);
}

int WheelController::_out(uint8_t * buf)
{
  return -1;
}

/*
 * Called when the rover's radius is updated.
 * Depends on the radius of the rover, updates the rover maxradius.
 */
void WheelController::updateMotionRadius()
{
  compute_center();
  compute_angle();
  compute_radius();

  if (rmotion->maxradius < wmotion.radius)
    rmotion->maxradius = wmotion.radius;

  compute_servoAngle();
}

/*
 * Called when the rover's velocity is updated.
 * Depends on the radius and the velocity (assumes radius is updated).
 */
void WheelController::updateMotionVelocity()
{
  compute_velocity();

  compute_wheelVelocity();
}


// Calculates the horizontal and vertical distances from the center of
// rotation of the wheel to the center of the wheel.
void WheelController::compute_center()
{
  wmotion.centerx = rmotion->radius + wattr.xpos;
  wmotion.centery = wattr.ypos;
}

void WheelController::compute_angle()
{
  switch (rmotion->drivemode)
  {
    case DRIVEMODE_NORMAL:
      if (!wattr.steerable)
      {
        wmotion.angle = HALF_PI;
      }
      else if (rmotion->radius > 0)
      {
        wmotion.angle = atan2(wmotion.centery, wmotion.centerx) + HALF_PI;
      }
      else
      {
        wmotion.angle = atan2(wmotion.centery, wmotion.centerx) - HALF_PI;
      }

      break;
    case DRIVEMODE_ROTATE:
      if (!wattr.steerable)
      {
        wmotion.angle = HALF_PI;
      }
      else if (wattr.xpos > 0)
      {
        wmotion.angle = wattr.centerangle + HALF_PI;
      }
      else
      {
        wmotion.angle = wattr.centerangle - HALF_PI;
      }

      break;
  }

  if (wattr.reverse) wmotion.angle += PI;

  // Bound the angle to +/- 2PI
  wmotion.angle = fmod(wmotion.angle, TWO_PI);

}

void WheelController::compute_radius()
{
  wmotion.radius = sqrt(pow(rmotion->radius + wattr.xpos, 2) +
                        pow(wattr.ypos, 2));
}

void WheelController::compute_velocity()
{
  switch (rmotion->drivemode)
  {
    case DRIVEMODE_NORMAL:
      wmotion.velocity = wmotion.radius * rmotion->velocity / abs(rmotion->radius);

      if (wattr.reverse) wmotion.velocity *= -1;

      // Check for situations where the wheel should turn in the opposite
      // direction than expected. This occurs when the wheel is
      // non-steerable or has a y-position of 0 and its wheel radius is
      // greater than the global rover radius.
      //
      // TODO: make this work with all wheels, not just the non-steerable
      // ones.
      if ( (!wattr.steerable || wattr.ypos == 0) &&
           (signum(rmotion->radius) * (rmotion->radius + wattr.xpos) < 0) )
      {
          wmotion.velocity *= -1;
      }

      break;
    case DRIVEMODE_ROTATE:
      wmotion.velocity = rmotion->rotation * wmotion.radius / rmotion->maxradius;
      break;
  }
}


void WheelController::compute_wheelVelocity()
{
    data.speed     = abs(wmotion.velocity) * WHEEL_MAX_SPEED;
    data.direction = (wmotion.velocity < 0) ? WHEEL_DIRECTION_BACKWARD :
                                              WHEEL_DIRECTION_FORWARD;
}

// Converts the wheel angle to a servo position between -90 and 90 degrees.
void WheelController::compute_servoAngle()
{
  float servoangle = 0;

  if (wattr.steerable) {
    servoangle = wmotion.angle - wattr.centerangle;

    // Bound anything that is too large or too small
    if ((wattr.xpos * wattr.ypos) < 0)
    {
      servoangle -= PI;
      if (servoangle < -PI) servoangle += TWO_PI;
    }
    else if (servoangle > PI)
    {
      servoangle -= TWO_PI;
    }
  }

  servoangle += HALF_PI;
  servoangle = abs(servoangle);

  data.servoangle = servoangle + 90;
}

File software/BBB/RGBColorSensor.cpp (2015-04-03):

#include "RGBColorSensor.h"

RGBColorSensor::RGBColorSensor(deviceManager & manager)
 : i2cDevice(TCS34725_ADDRESS, manager, 500), state(0) {}


void RGBColorSensor::init()
{
    //set integration time
    setIntegrationTime(0xC0);

    //set gain
    setGain(0x00);

}

void RGBColorSensor::setIntegrationTime(uint8_t integrationtime)
{
    /* Integration time options:
     * 2.4ms 0xFF
     * 24ms  0xF6
     * 50ms  0xEB
     * 101ms 0xD5
     * 154ms 0xC0
     * 700ms 0x00
     */

    /*
    switch (integrationtime)
    {
        case 0xFF: updateRate = 3;
        case 0xF6: updateRate = 24;
        case 0xEB: updateRate = 50;
        case 0xD5: updateRate = 101;
        case 0xC0: updateRate = 154;
        case 0x00: updateRate = 700;
    }
    */

    smbWriteByte(0x81, integrationtime);
}

void RGBColorSensor::setGain(uint8_t gain)
{
    /* Gain options:
     * 1x  0x00
     * 4x  0x01
     * 16x 0x02
     * 60x 0x03
     */

    smbWriteByte(0x8F, gain);
}

void RGBColorSensor::enable0()
{
    //enable internal oscillator
    smbWriteByte(0x80, 0x01);
}

void RGBColorSensor::enable1()
{
    //must wait at least 3ms after enable0

    //enable ADC
    smbWriteByte(0x80, 0x02 | 0x01);
}

void RGBColorSensor::disable()
{
    //turn off oscillator and ADC
    uint8_t en = smbReadByte(0x80);
    smbWriteByte(0x80, en & 0xFC);
}

void RGBColorSensor::_update()
{
    //check connectivity
    connected = (smbRead() >= 0);
    if (!connected)
    {
        state = 0;
        return;
    }

    switch (state)
    {
        case 0:	//not initialized
            init();
            enable0();
            state = 1;
            break;
        case 1: //enable ADC
            enable1();
            state = 2;
            break;
        case 2: //read color values
            data.c = smbReadWord(0x94);
            data.r = smbReadWord(0x96);
            data.g = smbReadWord(0x98);
            data.b = smbReadWord(0x9A);
            break;
    }

}

int RGBColorSensor::_out(uint8_t * buf)
{
    //prepare data for sending
    buf[0] = (data.r >> 8) & 0xFF;
    buf[1] = (data.r >> 0) & 0xFF;
    buf[2] = (data.g >> 8) & 0xFF;
    buf[3] = (data.g >> 0) & 0xFF;
    buf[4] = (data.b >> 8) & 0xFF;
    buf[5] = (data.b >> 0) & 0xFF;
    buf[6] = (data.c >> 8) & 0xFF;
    buf[7] = (data.c >> 0) & 0xFF;
    return 8;
}

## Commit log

2014-10-02 Added PCB Design Files
    Added the WIP BBB cape and the completed motor controller PCB files
    under the Eagle directory.
    [Rover BeagleBone Cape.brd, Rover BeagleBone Cape.sch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]
2014-10-02 Added BOM
2014-10-16 New Motor Controller Revision
    [Rover Motor Controller R1.brd, Rover Motor Controller R1.sch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]
2014-10-31 Added preliminary motor controller code
    Added Arduino code and PCB revisions
    [Rover BeagleBone Cape.brd, Rover BeagleBone Cape.sch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]
2014-10-31 Revised code
    [Rover Motor Controller R2.brd, Rover Motor Controller R2.sch]
2014-10-31 Added more motor controller code
2014-10-31 Started implementing PID code
2014-11-04 I2C Improvements
    Added SMBus function wrappers to the I2C device class, made I2C
    read/write functions more general, added IRTempSensor as a simple
    example of an I2C device derived class.
2014-11-04 Move resource files
    [mpu-9150_breakout.brd, mpu-9150_breakout.sch]
2014-11-06 Initial eagle files for several sensors
    [Rover IR Temp Sensor.brd, Rover IR Temp Sensor.sch, Rover Optical Dust Sensor.brd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]
2014-11-06 Fix content sizing
    Add “fit” attribute to content div
2014-11-06 Reorganize repository
    [Rover BeagleBone Cape.brd, Rover BeagleBone Cape.sch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]
2014-11-06 Revert 04bcd0d..a5c9ea5
    This rolls back to commit 04bcd0dcca32584b946719aa940ac024b91c2dbb.
    [Rover BeagleBone Cape.brd, Rover BeagleBone Cape.sch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]
2014-11-09 Remove BOM
2014-11-19 Make compatible with Arduino IDE
2014-11-20 Add ATtiny board descriptions
    Courtesy of http://highlowtech.org/?p=1695
2014-11-20 Motor Controller board revision
2014-11-20 Add PID library
    https://github.com/br3ttb/Arduino-PID-Library/
2014-11-20 Add servo library
    https://github.com/fri000/Servo8Bit
2014-11-21 Move IMU resources
    [mpu-9150_breakout.brd, mpu-9150_breakout.sch]
2014-11-21 Fully implement I2C register
2014-11-21 Fix Servo8Bit for ATtiny84
    [Motor-Controller.ino]
2014-11-21 Update Servo8Bit for ATtiny84
2014-12-09 Modify wheel struts
    [Rover.skp]
2014-12-10 Implement control register and motor control
2014-12-10 Add motor controller test program
2015-01-01 Begin defining inverse kinematics equations
2015-01-11 Add angle handling for wheels with a y-position of 0
2015-01-16 Use new Wheel API
2015-01-31 Begin work on motor controller R3
    [Rover Motor Controller R3.brd, Rover Motor Controller R3.sch]
2015-02-22 Work on suspension and chassis
2015-02-26 Add bolts to body lid
2015-03-10 Tweak dimensions for more accurate 3D printing
2015-03-23 Finally fix servo position calculations. Mostly. TODO: make less hacky
2015-03-23 Reorganize resource tree
    [mpu-9150_breakout.brd, mpu-9150_breakout.sch]
2015-03-23 Nothing to see here, move along
    [Rover Motor Controller R3.brd]
2015-03-23 Fix servo control code w/ new library (untested)
    [Motor-Controller.ino]
2015-03-26 Moar OOP, also comments
    Switched Wheel class to a nested class (more concise/logical). Started
    commenting code.
2015-03-28 Servo position is now from 0~180 deg
2015-03-28 Add serial port to control real motor controller
2015-03-31 Final work for April print
    [Body.skp, Body.stl, Lid.skp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]
2017-02-12 Add motor controller test
2017-02-17 Add motor controller R2 photos
2017-02-17 Add motor controller media

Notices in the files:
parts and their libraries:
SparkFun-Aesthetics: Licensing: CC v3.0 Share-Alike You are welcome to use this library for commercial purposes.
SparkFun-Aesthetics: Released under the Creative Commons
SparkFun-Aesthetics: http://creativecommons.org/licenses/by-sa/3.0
